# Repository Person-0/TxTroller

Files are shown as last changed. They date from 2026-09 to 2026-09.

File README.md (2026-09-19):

# **TxTroller**
*A Radio Receiver-to-USB HID Gamepad Adapter.*

# The Plan
This is a simple adapter that will allow older-style Radio transmitter / receiver combos to be used as video-game controllers using the USB HID Gamepad device class.

## Hardware
For the initial stages, this is being developed for the [`Radiolink R8EF`](https://www.radiolink.com/r8ef) receiver, which is an 8-channel receiver operating on the 2.4GHz frequency band.

As for the transmitter that will be the actual gamepad, It will be the [`Radiolink T8FB`](https://www.radiolink.com/t8fb) transmitter, which is a 2.4GHz 8 Channels RC Remote Transmitter.

The microcontroller that will be responsible for translating the SBUS signals from the receiver to the USB device class will be an [`XIAO RP2040`](https://wiki.seeedstudio.com/XIAO-RP2040/) due to it's small footprint and easy-to-use C/C++ SDK.

## PCB

The PCB has been designed using KiCAD 9.0. It is a 2 layer PCB with both top and bottom having thick signal traces and a ground fill.

PCB Schematics:

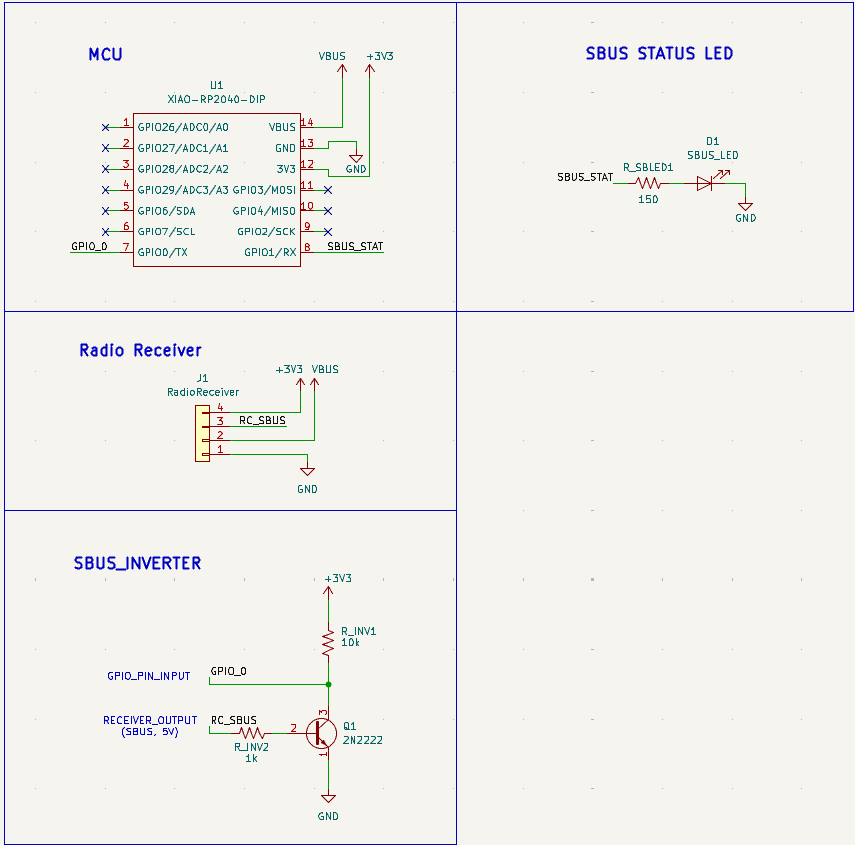
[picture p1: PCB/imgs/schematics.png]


PCB layout:

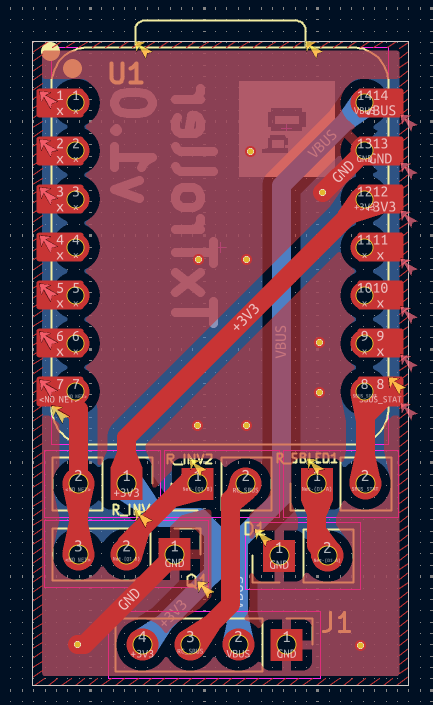
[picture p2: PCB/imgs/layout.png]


PCB Preview:

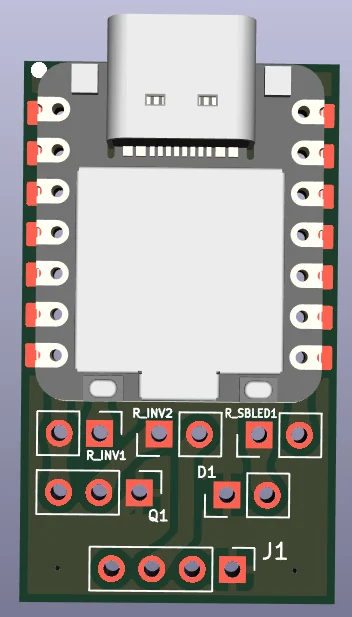
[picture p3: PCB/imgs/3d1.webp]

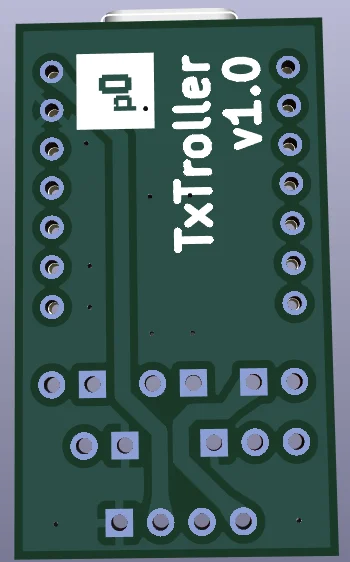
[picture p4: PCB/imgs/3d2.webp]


## 3D Case

The case has been designed in Fusion 360, with the `.f3z` available in the [/CAD](./CAD/) directory, along with the exported `.step` files of the top and bottom parts of the case in [/CAD/exports](./CAD/exports).

The case looks like this:

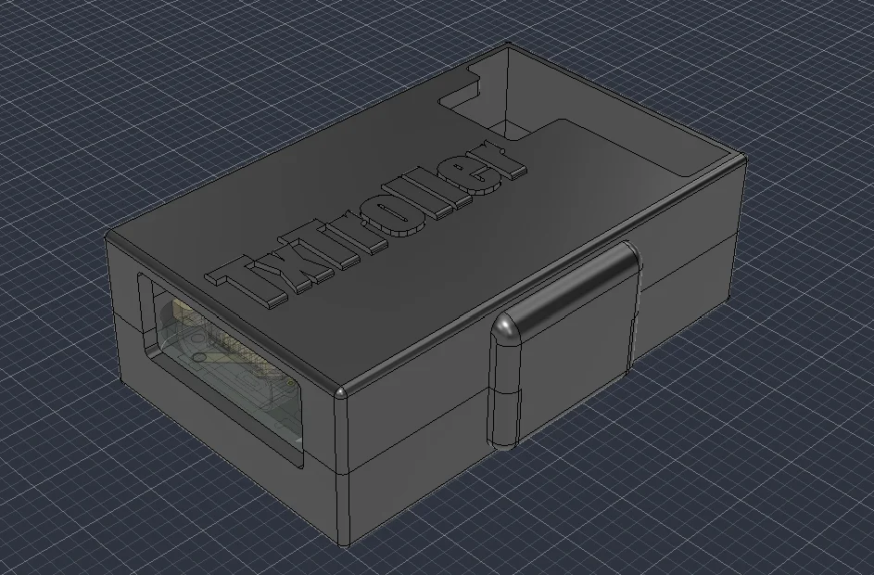
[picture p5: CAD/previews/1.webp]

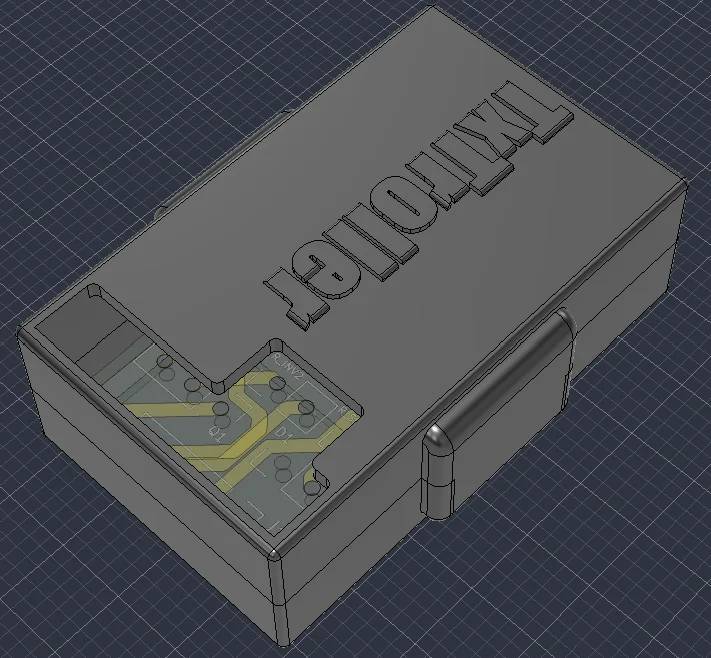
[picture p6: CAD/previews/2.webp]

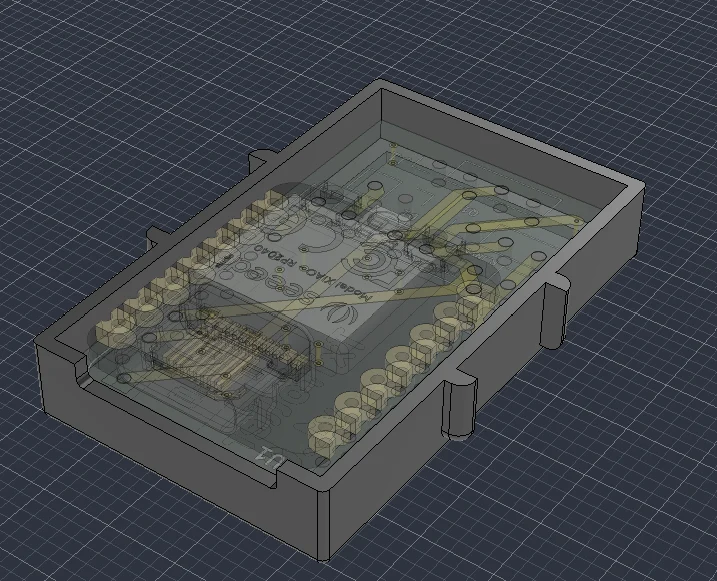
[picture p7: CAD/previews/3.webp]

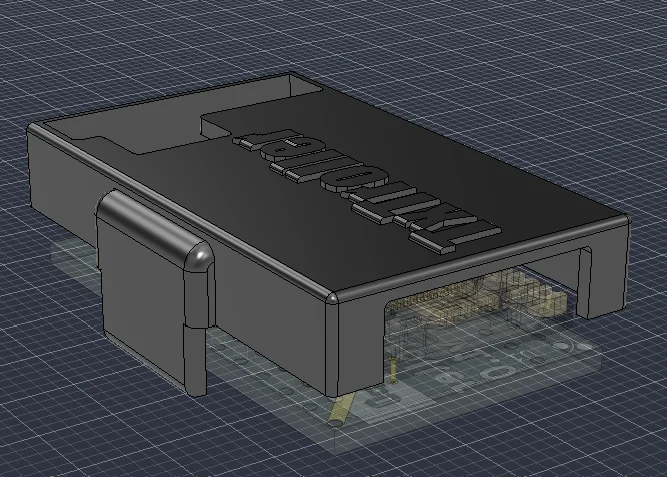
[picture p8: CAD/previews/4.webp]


The case has side extrusions for friction-fitting the top and bottom part of the case together.

## Firmware
*Originally modified from [raspberrypi/pico-examples/tree/master/usb/device/dev_hid_composite
](https://github.com/raspberrypi/pico-examples/tree/master/usb/device/dev_hid_composite).*

Checkout the [Firmware directory](./Firmware/) to view more information on button mappings, firmware compiling / flashing and testing the data received from the receiver.

## Ordering, BOM & 3d Printing

The PCB contains no SMD components or any other component that cannot be soldered using a normal soldering iron, hence no PCBA is required.

The PCB gerber .zip file is available in [PCB/exports/](./PCB/exports/).

### BOM Table
---

| S.No | Item Name | Description | Product URL | Qty | Unit Price ($) | Effective Price ($) |
| ---: | --- | --- | --- | --: | ---: | ---: |
| 1 | XIAO RP2040 | RP2040 Microcontroller | [XIAO RP2040](https://robocraze.com/products/seeed-studio-xiao-rp2040-development-board) | 1 | 6.14 | 6.14 |
| 2 | PCB | PCB manufacturing cost (5 qty) | [Lion Circuits](https://www.lioncircuits.com/quote) | 1 | 9.84 | 9.84 |
| 3 | 1k Ohm Resistor  | 1k Ohm Resistor - Pack of 10 | [1k Resistor Pack](https://robocraze.com/products/1k-resistor-pack-of-10) | 1 | 0.13 | 0.13 |
| 4 | 10k Ohm Resistor | 10k Ohm Resistor - Pack of 10  | [10k Resistor Pack](https://robocraze.com/products/10k-resistor-pack-of-10) | 1 | 0.14 | 0.14 |
| 5 | 100 Ohm Resistor | 100 Ohm Resistor - Pack of 10  | [100 Ohm Resistor Pack](https://robocraze.com/products/100-ohm-resistor-pack-of-10) | 1 | 0.16 | 0.16 |
| | | | | | **Total** | **16.41$** |

---

> *Note that the PCB states 150ohm resistor but we have only added 100ohm, this is because we can arrange 3 100 ohm resistors in such a way that the effective resistance becomes 150ohms (2parallel+1series).*

As for the 3d prints, the following files need to be printed **separately**:
- [CAD/exports/TxTroller_lid.step](./CAD/exports/TxTroller_lid.step)
- [CAD/exports/TxTroller_bottom.step](./CAD/exports/TxTroller_bottom.step)

Since they are designed to be friction fitted, no screws or heatset-inserts are needed.

## Credits
- https://github.com/controllercustom/dinput_tinyusb
- https://www.thingiverse.com/thing:6989033
- https://www.reddit.com/r/embedded/comments/1m6d1ei/gamepad_using_tinyusb_on_raspberry_pi_pico/
- https://github.com/gdsports/gamepad_tinyusb
- https://github.com/raspberrypi/pico-examples/tree/master/usb/device/dev_hid_composite

## Thank You! 😼💖

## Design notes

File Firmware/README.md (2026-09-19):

# TxTroller Firmware

> Modified from TinyUSB's [hid_composite example](https://github.com/hathach/tinyusb/tree/master/examples/device/hid_composite)

### Current mappings

These are the mappings I did for my T8FB transmitter.

---

| Gamepad | Transmitter |
| --- | --- |
| Right Joystick, X axis | Right stick, X axis |
| Right Joystick, Y axis | Right stick, Y axis |
| Left Joystick, X axis | Left stick, X axis |
| Left Joystick, Y axis | Left stick, Y axis |
| Axis `4` | Top right rotary |
| Axis `5` | Top left rotary |
| Button `A` | Top right switch (L position) |
| Button `B` | Top right switch (H position) |
| Button `X` | Top left switch  (L position) |
| Button `Y` | — |
---

`Button Y` can be included by making the ABXY buttons a combination of Top left and right switches but that would make it too complicated and also force that only a single button can be pressed at a time.

## Firmware Compiling / Flashing
- Install the [Raspberry Pi Pico VS Code extension](https://marketplace.visualstudio.com/items?itemName=raspberry-pi.raspberry-pi-pico)
- Clone this repository
- Open this folder (/firmware) in VS Code
- The extension will automatically detect your workspace and install necessary toolchains that will be used to compile the firmware
- Edit files if required
- Press `Compile` at the bottom bar to test whether the firmware compiles successfully
- Hold the boot tactile switch on the XIAO-RP040 while plugging it into your PC, this will allow us to flash the firmware
- Use the `Run` button next to the Compile button at the bottom bar to compile, flash the firmware to the Pico. After the firmware is flashed, the Pico will auto reboot and you will see the results directly.

## Special Notes

- Use the official Raspberry Pi Pico VS Code extension to build or flash the firmware as it will save you lots of time and config messes.

## Pin Reference
- GP00 - SBUS_LED_PIN
- GP01 - SBUS_PIN

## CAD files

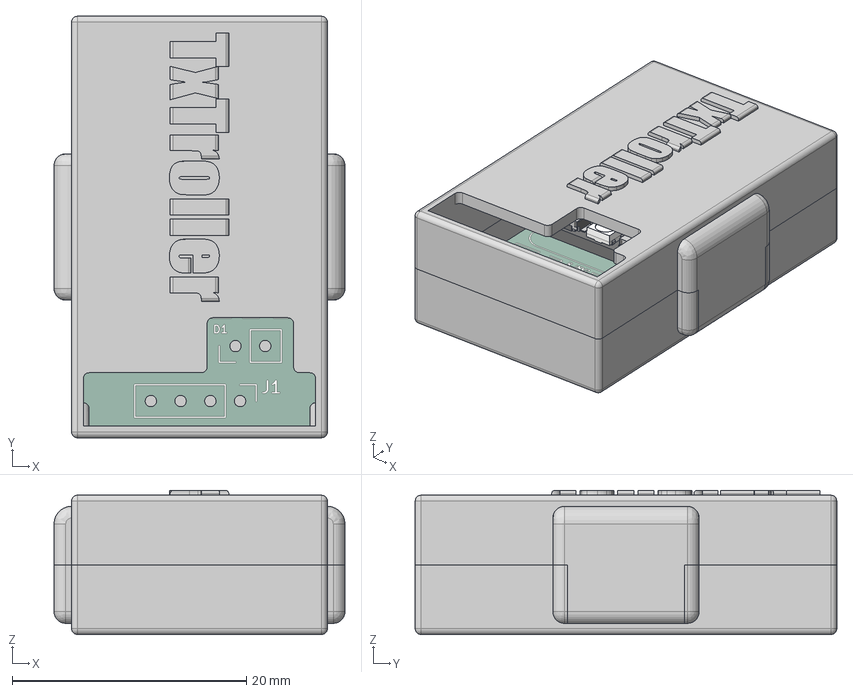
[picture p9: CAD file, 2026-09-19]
CAD/[DoNotPrint]_TxTroller_fullAssembly.step
24.9 x 36.0 x 12.3 mm
TxTroller_PCB
TxTroller_copper
TxTroller_via
TxTroller_silkscreen
TxTroller_soldermask
TxTroller_soldermask_1
TxTroller_silkscreen_1

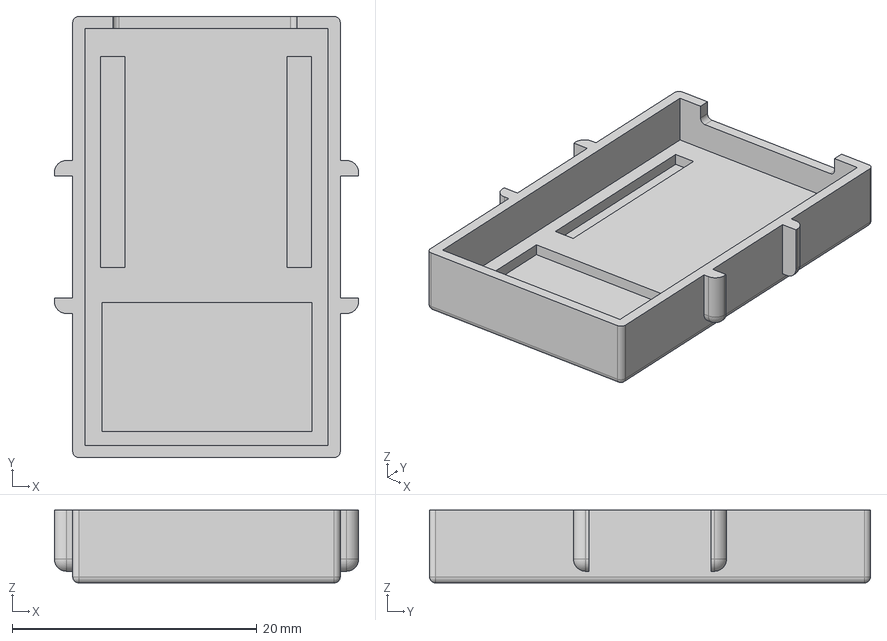
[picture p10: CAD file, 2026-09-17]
CAD/exports/TxTroller_bottom.step
24.9 x 36.0 x 5.95 mm

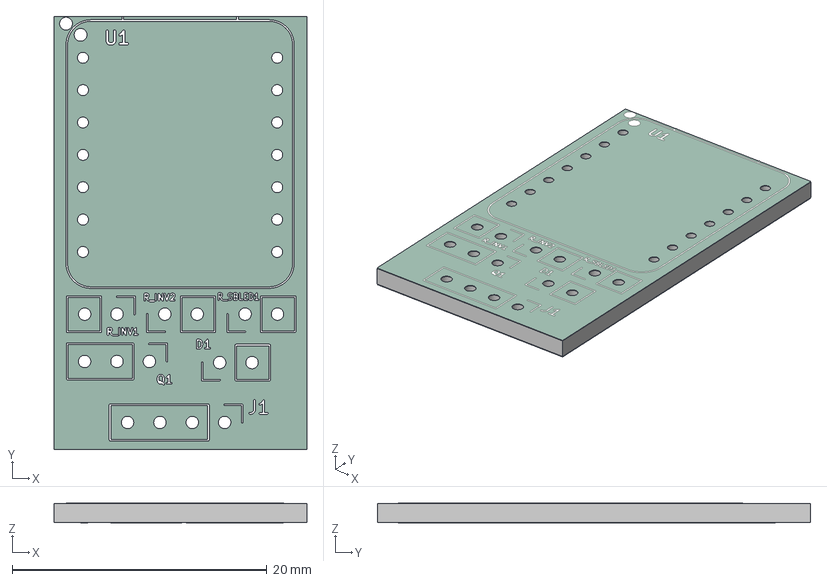
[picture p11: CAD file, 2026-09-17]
CAD/models/TxTroller_PCB.step
19.9 x 34.0 x 1.66 mm
TxTroller_copper
TxTroller_via
TxTroller_silkscreen x 2
TxTroller_soldermask x 2
TxTroller_PCB

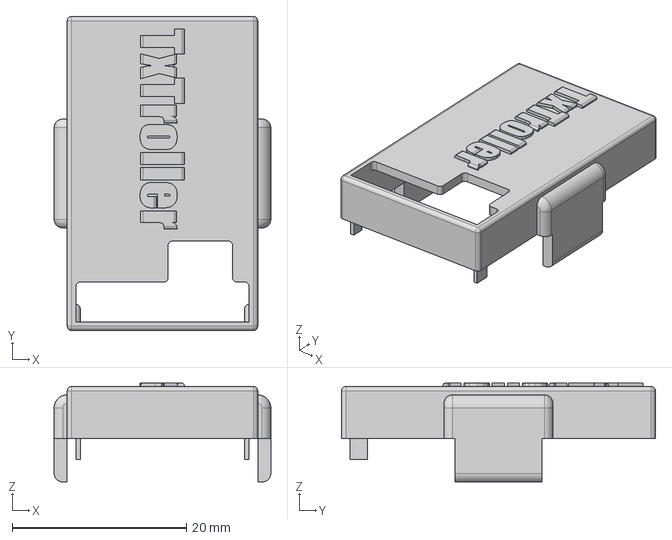
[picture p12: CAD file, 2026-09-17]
CAD/exports/TxTroller_lid.step
24.9 x 36.0 x 11.3 mm

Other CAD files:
CAD/TxTroller.f3z

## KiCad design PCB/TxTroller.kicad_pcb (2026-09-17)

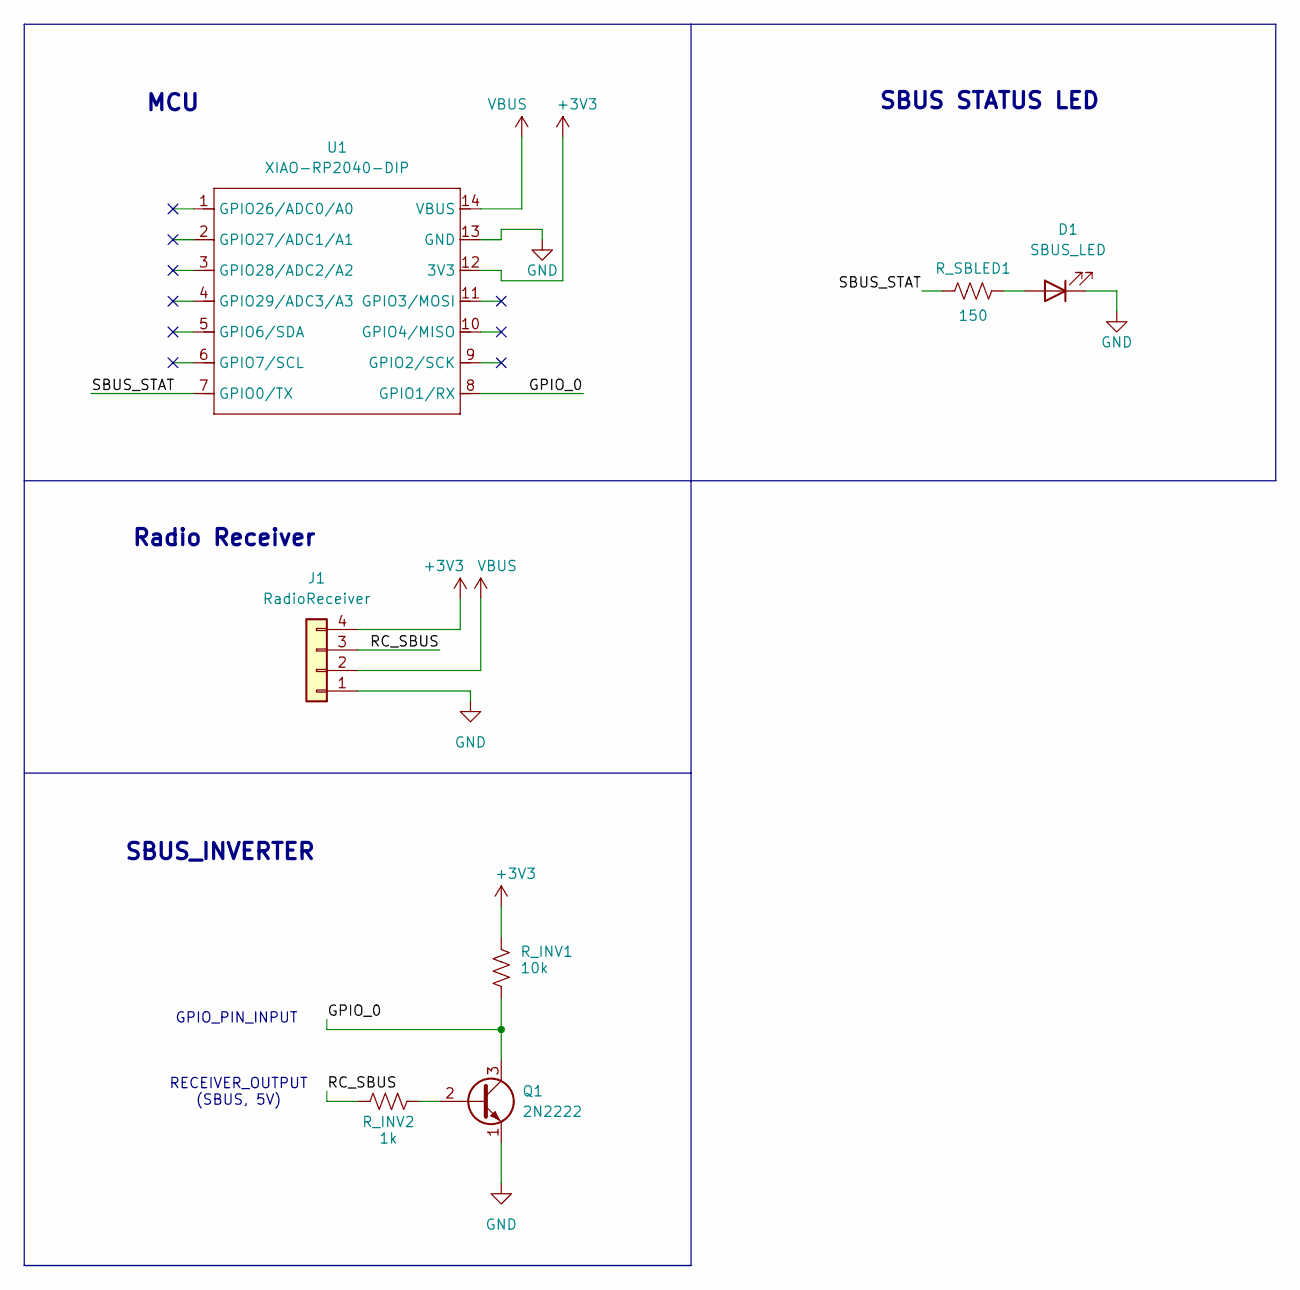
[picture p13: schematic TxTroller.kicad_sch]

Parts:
D1: SBUS_LED; PinHeader_1x02_P2.54mm_Vertical
J1: RadioReceiver; PinHeader_1x04_P2.54mm_Vertical
Q1: 2N2222; PinHeader_1x03_P2.54mm_Vertical
R_INV1: 10k; PinHeader_1x02_P2.54mm_Vertical
R_INV2: 1k; PinHeader_1x02_P2.54mm_Vertical
R_SBLED1: 150; PinHeader_1x02_P2.54mm_Vertical
U1: XIAO-RP2040-DIP

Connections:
+3V3: J1.4, R_INV1.1, U1.12 (3V3)
/<NO NET>: Q1.3 (C), R_INV1.2, U1.8 (GPIO1/RX)
/RC_SBUS: J1.3, R_INV2.2
/SBUS_STAT: R_SBLED1.2, U1.7 (GPIO0/TX)
GND: D1.1 (K), J1.1, Q1.1 (E), U1.13 (GND)
unnamed: D1.2 (A), R_SBLED1.1
unnamed: Q1.2 (B), R_INV2.1
VBUS: J1.2, U1.14 (VBUS)

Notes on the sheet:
MCU
SBUS_INVERTER
SBUS STATUS LED
GPIO_PIN_INPUT
RECEIVER_OUTPUT (SBUS, 5V)
Radio Receiver

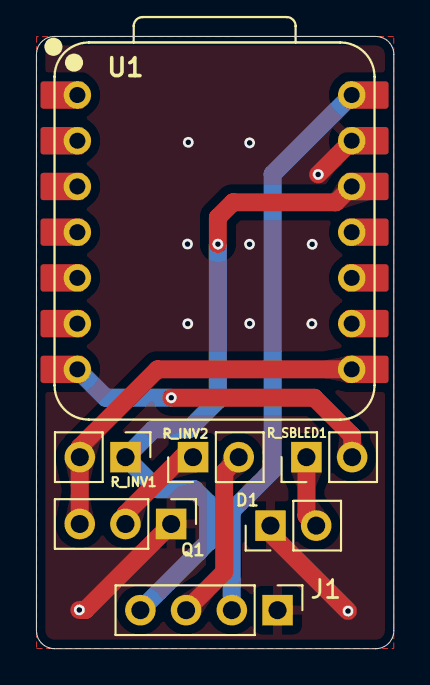
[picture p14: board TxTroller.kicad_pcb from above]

Board: 2 copper layers, 19.9 x 34.0 mm, 7 parts (0 on the bottom side), 8 nets.

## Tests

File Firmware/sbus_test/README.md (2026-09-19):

# Sbus Test
This is sample code that utilizes the sbus parser logic to log current values of all channels.

It logs the values to the serial console in `2500`ms intervals, which can be changed by editing the `LOG_INTERVAL` macro in [sbus_test.c](./sbus_test.c).

This is extremely helpful for figuring out the values which are actually being received instead of hit-n-trial-ing everyting.

# Channel Map

Channel map for reference that I tested on my transmitter.
```
1 -> right stick, x axis,   (  right  -> 1800, left   -> 200              )
2 -> right stick, y axis,   (  bottom -> 1800, top    -> 200              )
3 -> left  stick, y axis,   (  bottom -> 200 , top    -> 1800             )
4 -> left  stick, x axis,   (  right  -> 1800, left   -> 200              )
5 -> top right switch       (  l      -> 200 , mid    -> 1000, h -> 1800  )
6 -> top right rotary       (  left   -> 200 , right  -> 1800             )
7 -> top left switch        (  h      -> 1800, l      -> 200              )
8 -> top left rotary        (  left   -> 200 , right  -> 1800             )
```

### For compiling / flashing, please refer to the main firmware's compiling / flashing guide.

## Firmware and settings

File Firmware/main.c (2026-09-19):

#include <math.h>
#include <stdio.h>
#include <stdlib.h>
#include <string.h>

#include "config.h"
#include "pico/stdlib.h"
#include "sbus.h"
#include "tusb.h"
#include "usb_descriptors.h"

//--------------------------------------------------------------------+
// MACRO CONSTANT TYPEDEF PROTYPES
//--------------------------------------------------------------------+

/* Blink pattern
 * - 250 ms  : device not mounted
 * - 1000 ms : device mounted
 * - 2500 ms : device is suspended
 */
enum {
	BLINK_NOT_MOUNTED = 250,
	BLINK_MOUNTED = 1000,
	BLINK_SUSPENDED = 2500,
};

static uint32_t blink_interval_ms = BLINK_NOT_MOUNTED;

void led_blinking_task(void);
void hid_task(void);

/*------------- UTIL Fns -------------*/

#define board_millis() to_ms_since_boot(get_absolute_time())

void onboard_led_write(bool val) {
	gpio_put(ONBOARD_LED, 1 - val);  // led is active low
}

uint32_t wakeup_button_read() {
	return 0;  // todo: make it return 1 if tx btn was pressed
}

hid_gamepad_report_t LATEST_GAMEPAD_REPORT = {
	.x = 0,
	.y = 0,
	.z = 0,
	.rx = 0,
	.ry = 0,
	.rz = 0,
	.hat = GAMEPAD_HAT_CENTERED,	// not enough btns for dpad
	.buttons = 0					// btns
};

// [200,1800] >> [-128,127]
static int8_t sbus2hidVal(uint16_t data) {
    if (data < 172)  data = 172;
    if (data > 1811) data = 1811;
    return (int8_t)((((int32_t)(data - 172) * 254) / 1639) - 127);
}

void receiver_callback(uint8_t channel, uint16_t data) {
    switch (channel) {
        case 1:
			LATEST_GAMEPAD_REPORT.z = sbus2hidVal(data);
            break;
        case 2:
			LATEST_GAMEPAD_REPORT.rx = sbus2hidVal(data);
            break;
        case 3:
            LATEST_GAMEPAD_REPORT.y = -sbus2hidVal(data);
            break;
        case 4:
            LATEST_GAMEPAD_REPORT.x = sbus2hidVal(data);
            break;
        case 5:
			LATEST_GAMEPAD_REPORT.buttons &= ~((1 << 0) | (1 << 1));
            if (data < 900) {
                LATEST_GAMEPAD_REPORT.buttons |= (1 << 0);
            }
            else if (data > 1100) {
                LATEST_GAMEPAD_REPORT.buttons |= (1 << 1);
            }
            break;
        case 6:
			LATEST_GAMEPAD_REPORT.ry = sbus2hidVal(data);
            break;
        case 7:
			LATEST_GAMEPAD_REPORT.buttons &= ~(1 << 2);
            if (data < 900) {
                LATEST_GAMEPAD_REPORT.buttons |= (1 << 2);
            }
            break;
        case 8:
			LATEST_GAMEPAD_REPORT.rz = sbus2hidVal(data);
            break;
        default:
            printf("!!!!unrecognized channel index: %d\n", channel);
            break;
    }
}

/*------------- MAIN -------------*/
int main(void) {
	stdio_init_all();

	// setup onboard led
	gpio_init(ONBOARD_LED);
	gpio_set_dir(ONBOARD_LED, GPIO_OUT);
	gpio_put(ONBOARD_LED, 1);  // off

	// setup sbus
	setup_sbus();
	register_channel_callback(receiver_callback);

	// init device stack on configured roothub port
	tud_init(0);

	while (1) {
		tud_task();  // tinyusb device task
		led_blinking_task();
		hid_task();
	}
}

//--------------------------------------------------------------------+
// Device callbacks
//--------------------------------------------------------------------+

// Invoked when device is mounted
void tud_mount_cb(void) { blink_interval_ms = BLINK_MOUNTED; }

// Invoked when device is unmounted
void tud_umount_cb(void) { blink_interval_ms = BLINK_NOT_MOUNTED; }

// Invoked when usb bus is suspended
// remote_wakeup_en : if host allow us to perform remote wakeup
// Within 7ms, device must draw an average of current less than 2.5 mA from bus
void tud_suspend_cb(bool remote_wakeup_en) {
	(void)remote_wakeup_en;
	blink_interval_ms = BLINK_SUSPENDED;
}

// Invoked when usb bus is resumed
void tud_resume_cb(void) {
	blink_interval_ms = tud_mounted() ? BLINK_MOUNTED : BLINK_NOT_MOUNTED;
}

//--------------------------------------------------------------------+
// USB HID
//--------------------------------------------------------------------+

static void send_hid_report(void) {
	if (!tud_hid_ready()) return;
	tud_hid_report(REPORT_ID_GAMEPAD, &LATEST_GAMEPAD_REPORT, sizeof(LATEST_GAMEPAD_REPORT));
}

void hid_task(void) {
	// Poll every 10ms
	const uint32_t interval_ms = 10;
	static uint32_t start_ms = 0;
	if (board_millis() - start_ms < interval_ms) return;
	start_ms += interval_ms;
	if (!tud_hid_ready()) return;
	tud_hid_report(REPORT_ID_GAMEPAD, &LATEST_GAMEPAD_REPORT, sizeof(LATEST_GAMEPAD_REPORT));
}

// Invoked when received GET_REPORT control request
// Application must fill buffer report's content and return its length.
// Return zero will cause the stack to STALL request
uint16_t tud_hid_get_report_cb(
	uint8_t instance, uint8_t report_id,
	hid_report_type_t report_type, uint8_t* buffer,
	uint16_t reqlen
) {
	(void)instance;
	(void)report_id;
	(void)report_type;
	(void)buffer;
	(void)reqlen;
	return 0;
}

void tud_hid_set_report_cb(
	uint8_t instance, uint8_t report_id,
	hid_report_type_t report_type, uint8_t const* buffer,
	uint16_t bufsize
) {
	(void)instance;
	(void)report_id;
	(void)report_type;
	(void)buffer;
	(void)bufsize;
}

//--------------------------------------------------------------------+
// BLINKING TASK
//--------------------------------------------------------------------+
void led_blinking_task(void) {
	static uint32_t start_ms = 0;
	static bool led_state = false;

	// blink is disabled
	if (!blink_interval_ms) return;

	// Blink every interval ms
	if (board_millis() - start_ms < blink_interval_ms) return;  // not enough time
	start_ms += blink_interval_ms;

	onboard_led_write(led_state);
	led_state = 1 - led_state;  // toggle
}

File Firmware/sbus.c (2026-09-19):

#include <stdio.h>
#include "pico/stdlib.h"
#include "config.h"

/*
=============  
=============
 RECEIVER
 SBUS (already externally inverted)
=============
*/

// SBUS settings
#define SBUS_UART_IRQ   (SBUS_UART_ID == uart0) ? UART0_IRQ : UART1_IRQ
#define SBUS_BAUD_RATE  100000
#define SBUS_DATA_BITS  8
#define SBUS_STOP_BITS  2
#define SBUS_PARITY     UART_PARITY_EVEN

// SBUS parsing
volatile uint8_t sbus_index = 0;
volatile uint8_t sbus_byteCache[25];
volatile uint8_t sbus_bitStore[11];
static void (*channel_callback)(uint8_t, uint16_t) = NULL;

void set_sbus_led(bool status) {
    gpio_put(SBUS_LED_PIN, status);
}

static void parse_sbus_bytes() {
    channel_callback(1, (sbus_byteCache[1]       | sbus_byteCache[2]  << 8) & 0x07FF);
    channel_callback(2, (sbus_byteCache[2]  >> 3 | sbus_byteCache[3]  << 5) & 0x07FF);
    channel_callback(3, (sbus_byteCache[3]  >> 6 | sbus_byteCache[4]  << 2  | sbus_byteCache[5] << 10) & 0x07FF);
    channel_callback(4, (sbus_byteCache[5]  >> 1 | sbus_byteCache[6]  << 7) & 0x07FF);
    channel_callback(5, (sbus_byteCache[6]  >> 4 | sbus_byteCache[7]  << 4) & 0x07FF);
    channel_callback(6, (sbus_byteCache[7]  >> 7 | sbus_byteCache[8]  << 1  | sbus_byteCache[9] <<  9) & 0x07FF);
    channel_callback(7, (sbus_byteCache[9]  >> 2 | sbus_byteCache[10] << 6) & 0x07FF);
    channel_callback(8, (sbus_byteCache[10] >> 5 | sbus_byteCache[11] << 3) & 0x07FF);
}

static void on_uart_rx() {
    while (uart_is_readable(SBUS_UART_ID)) {
        set_sbus_led(1);
        uint8_t byte = uart_getc(SBUS_UART_ID);
        if (sbus_index == 0) {
            if (byte != 0x0F) {
                continue;
            }
        }
        sbus_byteCache[sbus_index] = byte;
        sbus_index++;
        if (sbus_index == 25) {
            parse_sbus_bytes();
            sbus_index = 0;
        }
    }
    set_sbus_led(0);
}

int setup_sbus() {
	gpio_init(SBUS_LED_PIN);
	gpio_set_dir(SBUS_LED_PIN, GPIO_OUT);
	gpio_put(SBUS_LED_PIN, 0);  // off

    uart_init(SBUS_UART_ID, SBUS_BAUD_RATE);
    gpio_set_function(SBUS_PIN, GPIO_FUNC_UART);
    uart_set_hw_flow(SBUS_UART_ID, false, false);
    uart_set_format(
        SBUS_UART_ID,
        SBUS_DATA_BITS,
        SBUS_STOP_BITS,
        SBUS_PARITY
    );
    uart_set_fifo_enabled(SBUS_UART_ID, true);
    irq_set_exclusive_handler(SBUS_UART_IRQ, on_uart_rx);
    irq_set_enabled(SBUS_UART_IRQ, true);
    uart_set_irq_enables(SBUS_UART_ID,true,false); // RX only

    printf("SBUS setup correctly\n");

    return 0;
}

void register_channel_callback(void (*callback)(uint8_t, uint16_t)) {
    channel_callback = callback;
    printf("receiver: channel callback registered\n");
}

void inject_sbus_bytes(uint8_t data[25]) {
    for (int i = 0; i < 25; i++) {
        sbus_byteCache[i] = data[i];
    }
    parse_sbus_bytes();
}

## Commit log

2026-09-17 finished schematics, PCB
    [TxTroller.kicad_pcb, TxTroller.kicad_sch, TxTroller_PCB.step]
2026-09-17 finished 3d printed case
    [TxTroller.f3z, TxTroller_bottom.step, TxTroller_lid.step]
2026-09-17 fixed pin assignments
    [TxTroller.kicad_pcb, TxTroller.kicad_sch]
2026-09-17 rounded edges of the PCB
    [TxTroller.kicad_pcb]
2026-09-17 fixed drc errs
    [TxTroller.kicad_pcb]
2026-09-18 added sbus_test for getting current channel values
2026-09-19 added support for xab buttons
2026-09-19 made buttons easier to read
2026-09-19 added BOM and ordering info
2026-09-19 enabled sbus led that was disabled for testing purposes
2026-09-19 add 3d print info, credits
2026-09-19 added full assembly step file
    [[DoNotPrint]_TxTroller_fullAssembly.step]
2026-09-19 moved full assembly step file to root of cad folder
    [[DoNotPrint]_TxTroller_fullAssembly.step]
2026-10-10 readme cleanup, added assembly instructions
